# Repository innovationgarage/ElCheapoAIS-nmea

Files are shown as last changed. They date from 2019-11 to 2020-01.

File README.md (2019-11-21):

# About

ElCheapoAIS-nmea is a relay for AIS messages, sending received AIS messages, including your own position, speed etc
to land using your regular (satellite) internet connection.

# User documentation
## Hardware installation

* Ensure you have the latest version of the TinyTracker software on a USB stick attached to the USB port next to the network port.
* Connect the A, B and GND screw headers to an NMEA 0183 output on your AIS or NMEA hub
* Connect the USB cable to a USB charger
* Optionally connect a network cable

## Firewall configuration

You need to open outgoing tcp traffic to the ports 1026 and 1024 to elcheapoais.innovationgarage.tech (93.188.234.96).

## Default configuration

* NMEA bus
  * 38400 baud, 8bit, no flow control, 1 stop bit (8N1).

* AIS downsampling
  * Lowest of a total of 100 messages / sec or 10 messages / sec / mmsi.

# Production documentation

## Hardware

* Base board: [OrangePI Zero](https://www.aliexpress.com/item/32915378874.html)
* Screen: [TTGO OLED ESP8622 SH1106](https://www.aliexpress.com/item/32991442463.html?spm=a2g0s.9042311.0.0.27424c4d5SbjHq)
  * Running [TTyGO](https://innovationgarage.github.io/TTyGO/)
  * Connected to UART0 RX, TX and GND,+5V
* NMEA dongle: [RS485/422 usb dongle](https://www.aliexpress.com/item/32888122294.html)
  * Connected to internal USB port
* USB flash memory
  * Connected to external USB port (note: one of the internal ones does NOT work in u-boot!)

## Generating a USB software image

* Download the latest Armbian image and write it to a USB memory using dd.
* Boot an OrangePi using this USB with the serial port connected to a PC.
* Log in, then clone and install this repo:

    ```
    git clone --branch dbus-0.1 git@github.com:innovationgarage/ElCheapoAIS-nmea.git
    cd ElCheapoAIS-nmea
    ./install.sh --branch=dbus-0.1
    ```
    
Note that you do not need to make a full image of the USB stick when making copies for the copy to boot - it is enough to copy the files to a new filesystem (on a lone partition), as long as you update rootfs in /boot/armbianEnv.txt to point to /dev/sda.

## Installing the bootloader on a device
OrangePI is not able to boot from USB by default. To enable this you have to [write a copy of the u-boot boot loader to the on-board NOR-flash](https://forum.armbian.com/topic/8111-orange-pi-zero-plus-spi-nor-flash-anyone-know-how-to-configure-for-booting/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).

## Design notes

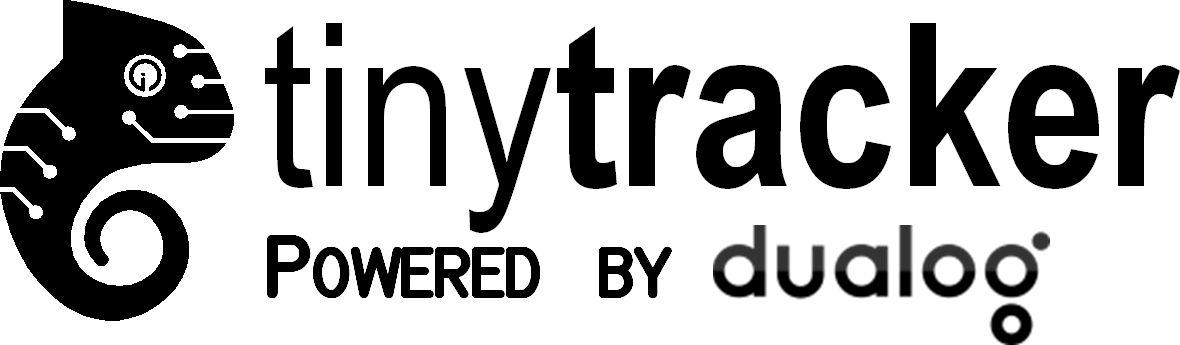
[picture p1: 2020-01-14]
case/Wooden Multicase/labels/main.PNG

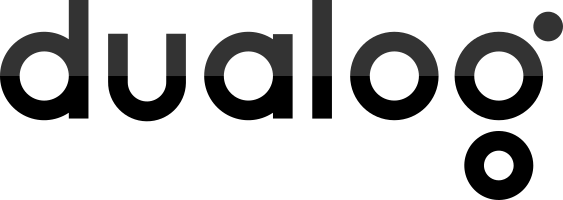
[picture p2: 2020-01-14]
case/Wooden Multicase/dualog.png

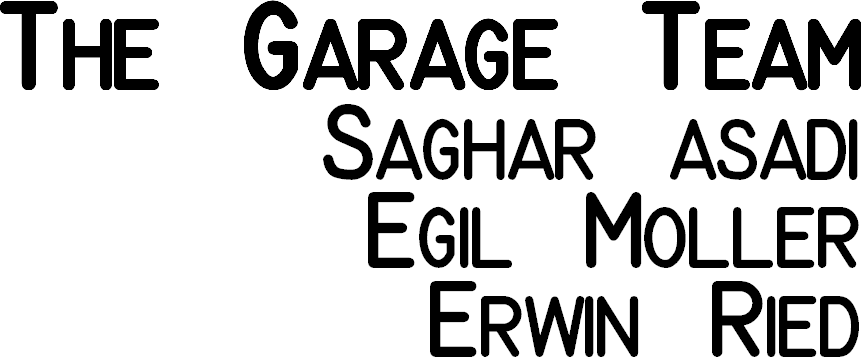
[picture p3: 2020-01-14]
case/Wooden Multicase/labels/team.PNG

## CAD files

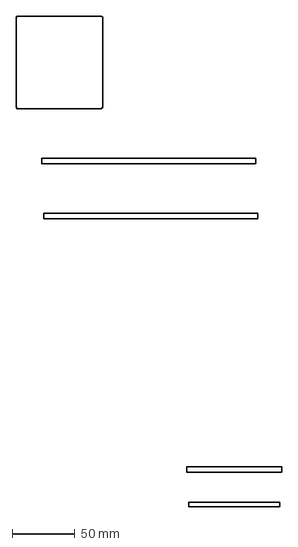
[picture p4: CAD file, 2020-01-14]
case/Wooden Multicase/dxf/inside.dxf
210.9 x 389.7 mm

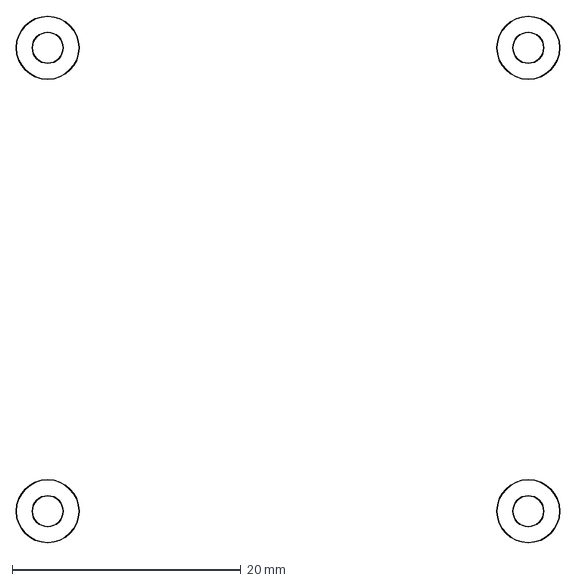
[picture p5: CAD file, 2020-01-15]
case/Wooden Multicase/prototype/orangepi_footprint.dxf
47.5 x 46.0 mm

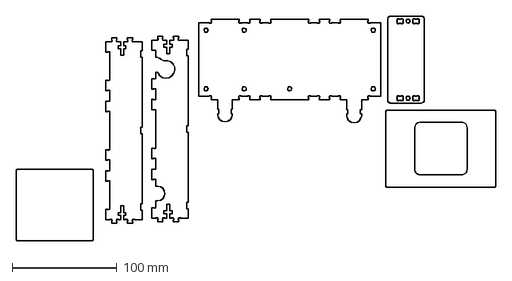
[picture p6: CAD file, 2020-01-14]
case/Wooden Multicase/dxf/outside.dxf
458.0 x 214.7 mm

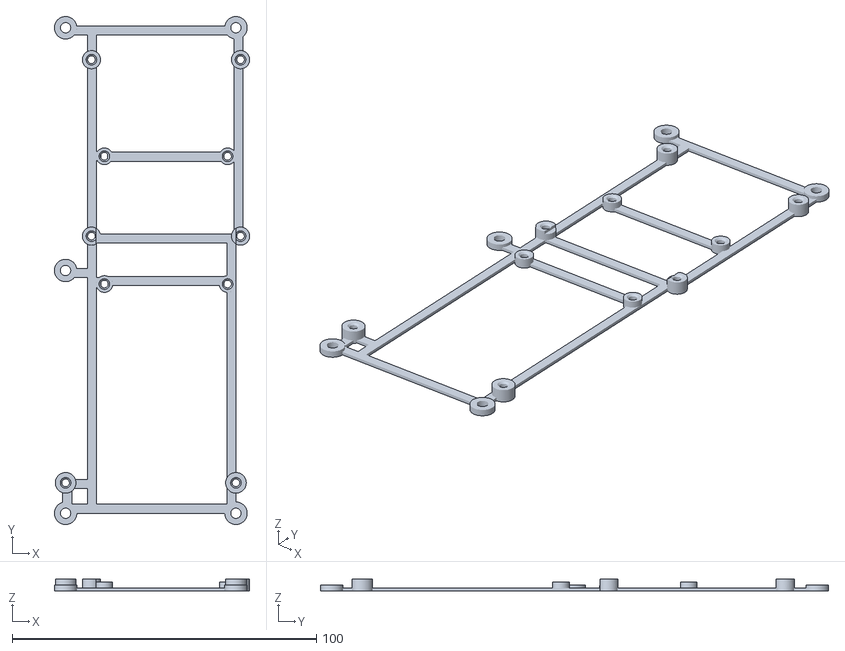
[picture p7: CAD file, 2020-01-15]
case/Wooden Multicase/prototype/system_holder_plastic.stl
64.2 x 167.0 x 4.00

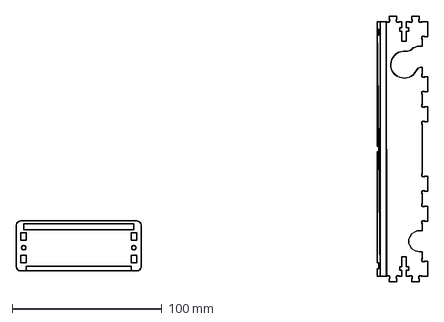
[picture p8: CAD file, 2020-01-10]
case/Wooden Multicase/dxf/all2.dxf
274.6 x 177.2 mm

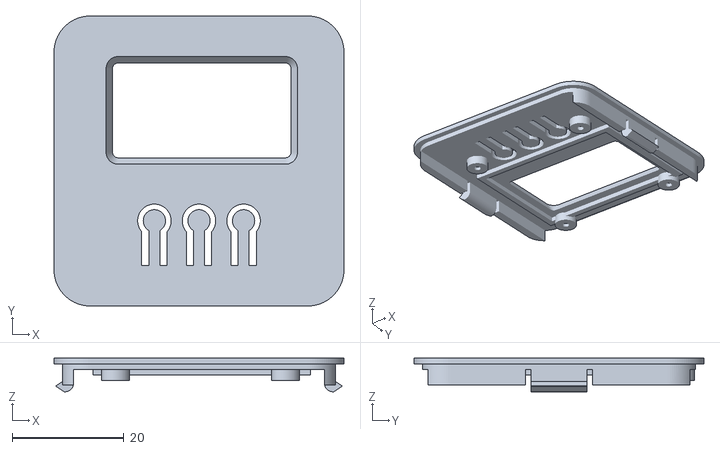
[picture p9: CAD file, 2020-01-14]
case/Wooden Multicase/prototype/lcd_cover_plastic.stl
52.0 x 52.0 x 6.02

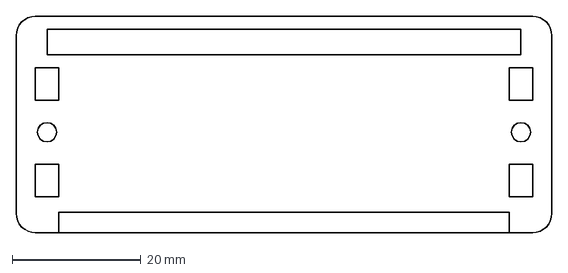
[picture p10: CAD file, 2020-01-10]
case/Wooden Multicase/dxf/side.dxf
83.2 x 33.6 mm

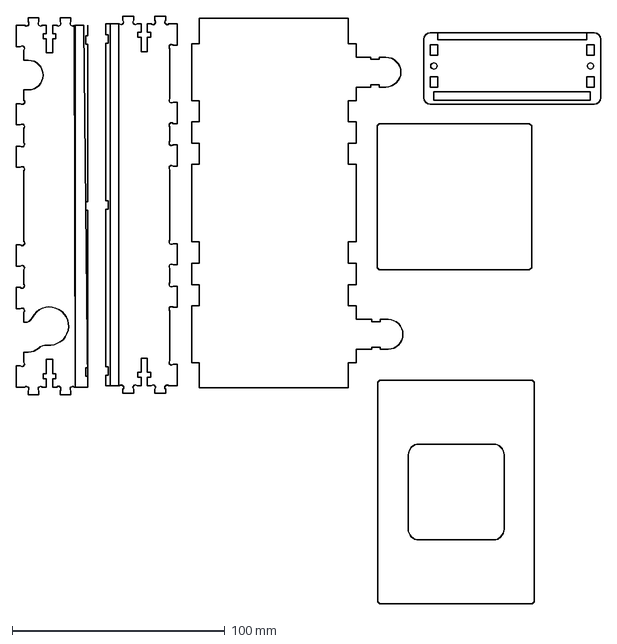
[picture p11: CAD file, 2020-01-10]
case/Wooden Multicase/dxf/all.dxf
274.6 x 276.1 mm

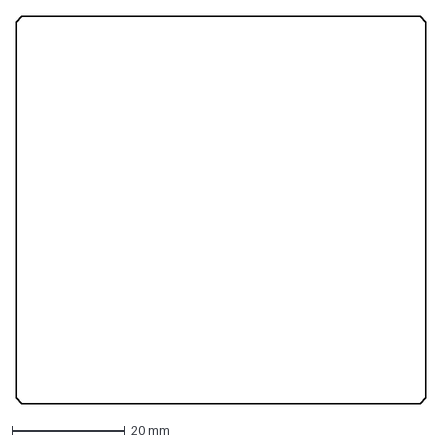
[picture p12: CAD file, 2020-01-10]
case/Wooden Multicase/dxf/slider_cable.dxf
72.6 x 68.6 mm

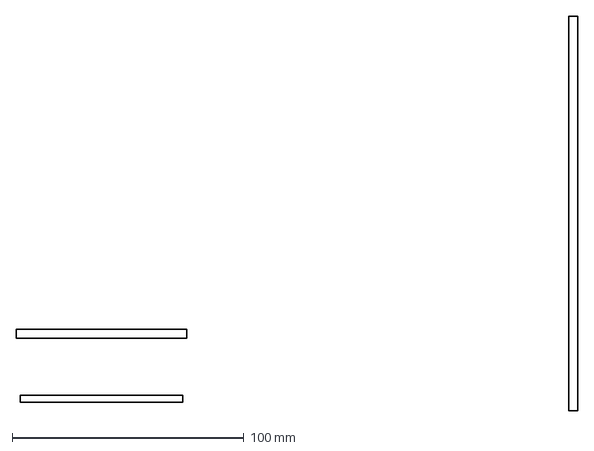
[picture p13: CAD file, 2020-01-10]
case/Wooden Multicase/dxf/all3.dxf
242.2 x 170.0 mm

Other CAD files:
case/OrangeZero/source-ttgoterm/OldVersions/assembly.0005.iam
case/OrangeZero/source-ttgoterm/OldVersions/top_lcd.0009.ipt
case/OrangeZero/source-ttgoterm/assembly.iam
case/OrangeZero/source-ttgoterm/top_lcd.ipt
case/OrangeZero/source/OldVersions/bottom_part.0026.ipt
case/OrangeZero/source/bottom_part.ipt
case/Wooden Multicase/OldVersions/cover_components.0004.ipt
case/Wooden Multicase/OldVersions/cover_wires.0004.ipt
case/Wooden Multicase/OldVersions/disassembled.0003.iam
case/Wooden Multicase/OldVersions/drawings_easel.0002.ipt
case/Wooden Multicase/OldVersions/side_bottom.0010.ipt
case/Wooden Multicase/OldVersions/side_side.0010.ipt
case/Wooden Multicase/OldVersions/side_top.0011.ipt
case/Wooden Multicase/cover_components.ipt
case/Wooden Multicase/cover_wires.ipt
case/Wooden Multicase/disassembled.iam
case/Wooden Multicase/drawings_easel.ipt
case/Wooden Multicase/prototype/Case.iam
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

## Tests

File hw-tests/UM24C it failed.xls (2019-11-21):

Voltage-Current
Time | Voltage(V) | Current(A) | D+(V) | D-(V) | Date
14:47:00 | 5.19 | 0 | 2.83 | 2.84 | 2019-11-18
14:47:01 | 5.18 | 0 | 2.83 | 2.84 | 2019-11-18
14:47:02 | 5.19 | 0 | 2.83 | 2.84 | 2019-11-18
14:47:03 | 5.18 | 0 | 2.83 | 2.84 | 2019-11-18
14:47:04 | 5.18 | 0 | 2.83 | 2.84 | 2019-11-18
14:47:05 | 5.18 | 0 | 2.83 | 2.84 | 2019-11-18
14:47:06 | 5.19 | 0 | 2.83 | 2.84 | 2019-11-18
14:47:07 | 5.18 | 0 | 2.83 | 2.84 | 2019-11-18
14:47:08 | 5.18 | 0 | 2.83 | 2.84 | 2019-11-18
14:47:09 | 5.18 | 0 | 2.83 | 2.84 | 2019-11-18
14:47:10 | 5.19 | 0 | 2.83 | 2.84 | 2019-11-18
14:47:11 | 5.18 | 0 | 2.83 | 2.84 | 2019-11-18
14:47:12 | 5.19 | 0 | 2.83 | 2.84 | 2019-11-18
14:47:13 | 5.16 | 0.226 | 2.82 | 2.83 | 2019-11-18
14:47:14 | 5.15 | 0.293 | 2.82 | 2.83 | 2019-11-18
14:47:15 | 5.15 | 0.32 | 2.82 | 2.83 | 2019-11-18
14:47:16 | 5.15 | 0.323 | 2.82 | 2.83 | 2019-11-18
14:47:17 | 5.15 | 0.334 | 2.82 | 2.83 | 2019-11-18
14:47:18 | 5.15 | 0.344 | 2.82 | 2.83 | 2019-11-18
14:47:19 | 5.15 | 0.342 | 2.82 | 2.83 | 2019-11-18
14:47:20 | 5.15 | 0.346 | 2.82 | 2.83 | 2019-11-18
14:47:21 | 5.14 | 0.406 | 2.81 | 2.82 | 2019-11-18
14:47:22 | 5.16 | 0.258 | 2.82 | 2.83 | 2019-11-18
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

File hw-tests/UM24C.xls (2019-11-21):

Voltage-Current
Time | Voltage(V) | Current(A) | D+(V) | D-(V) | Date
11:22:50 | 5.19 | 0 | 0 | 0 | 2019-11-18
11:22:51 | 5.19 | 0 | 0 | 0 | 2019-11-18
11:22:52 | 5.19 | 0 | 0 | 0 | 2019-11-18
11:22:53 | 5.19 | 0 | 0 | 0 | 2019-11-18
11:22:54 | 5.19 | 0 | 0 | 0 | 2019-11-18
11:22:55 | 5.19 | 0 | 0 | 0 | 2019-11-18
11:22:56 | 5.18 | 0 | 0 | 0 | 2019-11-18
11:22:57 | 5.19 | 0 | 0 | 0 | 2019-11-18
11:22:58 | 5.19 | 0 | 0 | 0 | 2019-11-18
11:22:59 | 5.19 | 0 | 0 | 0 | 2019-11-18
11:23:00 | 5.19 | 0 | 0 | 0 | 2019-11-18
11:23:01 | 5.19 | 0 | 0 | 0 | 2019-11-18
11:23:02 | 5.19 | 0 | 0 | 0 | 2019-11-18
11:23:03 | 5.19 | 0 | 0 | 0 | 2019-11-18
11:23:04 | 5.19 | 0 | 0 | 0 | 2019-11-18
11:23:05 | 5.19 | 0 | 0 | 0 | 2019-11-18
11:23:06 | 5.19 | 0 | 0 | 0 | 2019-11-18
11:23:07 | 5.19 | 0 | 0 | 0 | 2019-11-18
11:23:08 | 5.19 | 0 | 0 | 0 | 2019-11-18
11:23:09 | 5.19 | 0 | 0 | 0 | 2019-11-18
11:23:10 | 5.19 | 0 | 0 | 0 | 2019-11-18
11:23:11 | 5.18 | 0 | 0 | 0 | 2019-11-18
11:23:12 | 5.19 | 0 | 0 | 0 | 2019-11-18
11:23:13 | 5.19 | 0 | 0 | 0 | 2019-11-18
11:23:14 | 5.19 | 0 | 0 | 0 | 2019-11-18
11:23:15 | 5.19 | 0 | 0 | 0 | 2019-11-18
11:23:16 | 5.19 | 0 | 0 | 0 | 2019-11-18
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

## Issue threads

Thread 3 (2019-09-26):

Prototype platform

eried, 2019-09-26:
* https://ninjamock.com/home/index?v=2
Looks hand drawn. In case we cannot do the fake integration with apps landpage it is a good option

* https://moqups.com/#tour
It is mostly graphical only. Does not provide realistic UI

* https://www.smartdraw.com/website-wireframe/mockup-tool.htm
It is like visio online

* https://balsamiq.com/
Similar to moqups, only graphical

* https://www.invisionapp.com/#tour
This is really good for the interactions, but not for generating the UI

* https://www.uxpin.com/

* https://www.fluidui.com/

* https://www.justinmind.com/

* https://prottapp.com/

* Adobe XD

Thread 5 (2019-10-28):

NOR flash boot loader

redhog, 2019-10-28:
Write boot loader to on-board NOR flash so that the device can boot from e.g. USB:
https://forum.armbian.com/topic/8111-orange-pi-zero-plus-spi-nor-flash-anyone-know-how-to-configure-for-booting/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

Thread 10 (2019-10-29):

USB boot

redhog, 2019-10-29:
USB storage devices do NOT need to have proper images copied to them. It is enough to make an ext4 filesystem partition and copy the root filesystem files there using rsync. However, the filesystem does need to have the correct UUID(!) as the kernel command line uses that to find the root fs(!!). Here's how to read and to set that:

http://www.sudo-juice.com/how-to-change-the-uuid-of-a-linux-partition/

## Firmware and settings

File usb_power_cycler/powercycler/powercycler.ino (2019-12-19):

#define PIN_POWER 1
#define PIN_SETUP A2 // pin 4
#define PIN_LED 0
#define delay(x) delay(x/6.7)

unsigned long hours_to_wait_in_ms, next_reset;
const int measurements = 10; // Read the configuration value using N samples
const int blinks_before_reset = 30,
          blinks_speed_on = 10, blinks_speed_off = 300;
const int blinks_hours_on_0 = 1000,
          blinks_hours_on = 200,
          blinks_hours_off = 200;

void blink(int on = blinks_speed_on, int off = blinks_speed_off, bool fade = true)
{
  if (fade)
  {
    for (int i = 0; i < 255; i += 5)
    {
      analogWrite(PIN_LED, i);
      delay(7);
    }
    delay(on);
    for (int i = 0; i < 255; i += 5)
    {
      analogWrite(PIN_LED, 255 - i);
      delay(8);
    }
    digitalWrite(PIN_LED, LOW);
    delay(off);
  }
  else
  {
    digitalWrite(PIN_LED, HIGH);
    delay(on);
    digitalWrite(PIN_LED, LOW);
    delay(off);
  }
}

void blink(bool fade)
{
  blink(blinks_speed_on, blinks_speed_off, fade);
}

void setup() {
  OSCCAL = 181;
  pinMode(PIN_LED, OUTPUT);

  // blink test
  /*while(true)
    {
    int t = map(analogRead(PIN_SETUP),0,1024,10,1000);
    blink(t,400);
    }*/

  pinMode(PIN_POWER, OUTPUT);
  digitalWrite(PIN_POWER, LOW); // Start powered

  // Read the current configuration for times
  int v = 0;
  for (int i = 0; i < measurements; i++)
  {
    v += analogRead(PIN_SETUP);
    delay(10);
  }

  int hours = max(1, min(24, map(v / measurements, 0, 1024, 0, 25))); // Min 1 hour, max 24 hour
  hours_to_wait_in_ms = hours * 60 * 60 * 1000; // In millis

  // Blink the number of hours in setup
  for (int i = 0; i < hours; i++)
    blink(i == 0 ? blinks_hours_on_0 : blinks_hours_on, blinks_hours_off);

    digitalWrite(PIN_POWER, HIGH); // Start powered
}

void loop()
{
  next_reset = millis() + hours_to_wait_in_ms - (2 * blinks_before_reset * (blinks_speed_on + blinks_speed_off));

  do
  {
    delay(60000-blinks_speed_off-blinks_speed_on); // Blink every minute
    blink(false);
  }
  while (millis() < next_reset);
  while (true);

  // Do the reset now
  for (int i = 0; i < blinks_before_reset; i++)
    blink();

  digitalWrite(PIN_POWER, LOW); // Power down
  blink(blinks_before_reset * (blinks_speed_on + blinks_speed_off), 0); // Keep the light on while it resets
  digitalWrite(PIN_POWER, HIGH); // Power on
}

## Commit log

2019-11-20 Recorded consumption data
    [UM24C it failed.xls, UM24C.xls]
2019-12-19 New case
    [Case.0002.iam, Case.iam, cover.0002.ipt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]
2019-12-27 Create case2.svg
    Improved design with bigger holes and cleaner details
2019-12-27 Modular cover for TTyGO
    [lcd_cover.ipt]
2020-01-10 New-newer wooden case
    [Case.0002.iam, Case.0014.iam, Case.iam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]
2020-01-13 Corrected prototype
    [Case.0014.iam, Case.0015.iam, all.dxf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]
2020-01-14 Final design
    [assembled_case.0018.iam, assembled_case.0020.iam, assembled_case.iam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]
2020-01-14 Case labels
2020-01-14 LCD holder
    [lcd_cover_plastic.0001.ipt, lcd_cover_plastic.0003.ipt, lcd_cover_plastic.ipt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]
2020-01-15 New version
    [assembled_case.0020.iam, assembled_case.0021.iam, assembled_case.iam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]
